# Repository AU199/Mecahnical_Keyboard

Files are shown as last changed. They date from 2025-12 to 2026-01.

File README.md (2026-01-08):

# Mecahnical Keyboard
I made this projects because I wanted to learn how software and hardware come together inside something as simple keyboard (Which I found wasn't simple at all). I wanted to also learn how to make a PCB and how to CAD with better practices. This is a Mechanical keyboard that utilizes both a main chip and a "slave" chip (a chip made to work as if it were just an i/o extender). This uses a diode-matrix for the sensing and uses the SDA and SCL channels on the "slave" chip to read and understand. 

BOM (Used an program for this to convert to a table in a .md file)
| Item | Description | Quantity | Total Price | shipping | Link | Running Total | Comments |
| --- | --- | --- | --- | --- | --- | --- | --- |
| Kailh Hotswap Switches (70 PCS) | Need for the mechanical Keyboard switches | 1 | $4.71 | | https://www.aliexpress.us/item/3256807290300019.html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 | $4.71 | |
| 0.91 INCH OLED DISPLAY MODULE | Display Module added for display functionallity | 1 | $2.40 | | https://www.aliexpress.us/item/3256807115924372.html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 | $7.07 | |
| MCP23017-E/SO | I/O expander that I need in order to make the full keyboard | 1 | $4.99 | | https://www.aliexpress.us/item/3256810374801839.html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 | $12.06 | |
| XIAO-nRF52840 | Main Chip of this keyboard | 1 | $11.77 | | https://www.aliexpress.us/item/3256808117851584.html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 | $23.83 | |
| PCB & PCBA | The total price for both making the PCB and the PCBA | 1 | $42.01 | $91.28 (FedEx Express (DDP), I can't do anything about the price, there is also a 10 dollar discount as such the grand total comes to be $123.85) | JLCPCB (CAN'T PROVIDE A LINK) | $147.68 | includes Sales tax, shipping and customes duties  |
| Key Switch | Needed for typing | 1 | $3.23 | | https://www.aliexpress.us/item/3256806499127042.html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 | $150.91 | |
| Key Caps | Needed to put on the swtiches | 1 | $8.77 | | https://www.aliexpress.us/item/3256804183268436.html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 | $159.68 | |
| Resistor Network (6PCS) | Pull up Resistor chain | 1 | $1.79 | | https://www.aliexpress.us/item/3256806684196291.html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 | $161.47 | |
| Soldering Wire (Lead Free) | Needed For Soldering | 1 | $3.65 | | https://www.aliexpress.us/item/3256810239367550.html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 | $165.12 | |
| Stabalizers | Needed for the larger keys | 1 | $6.77 | $16.50 | https://www.aliexpress.us/item/2251832533420646.html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 | $188.39 | includes Sales tax and shipping |
| |
# SHIPPING PRICE PROOF (Price is a little different since I had to make a new order, but the delivery method is still the same)   
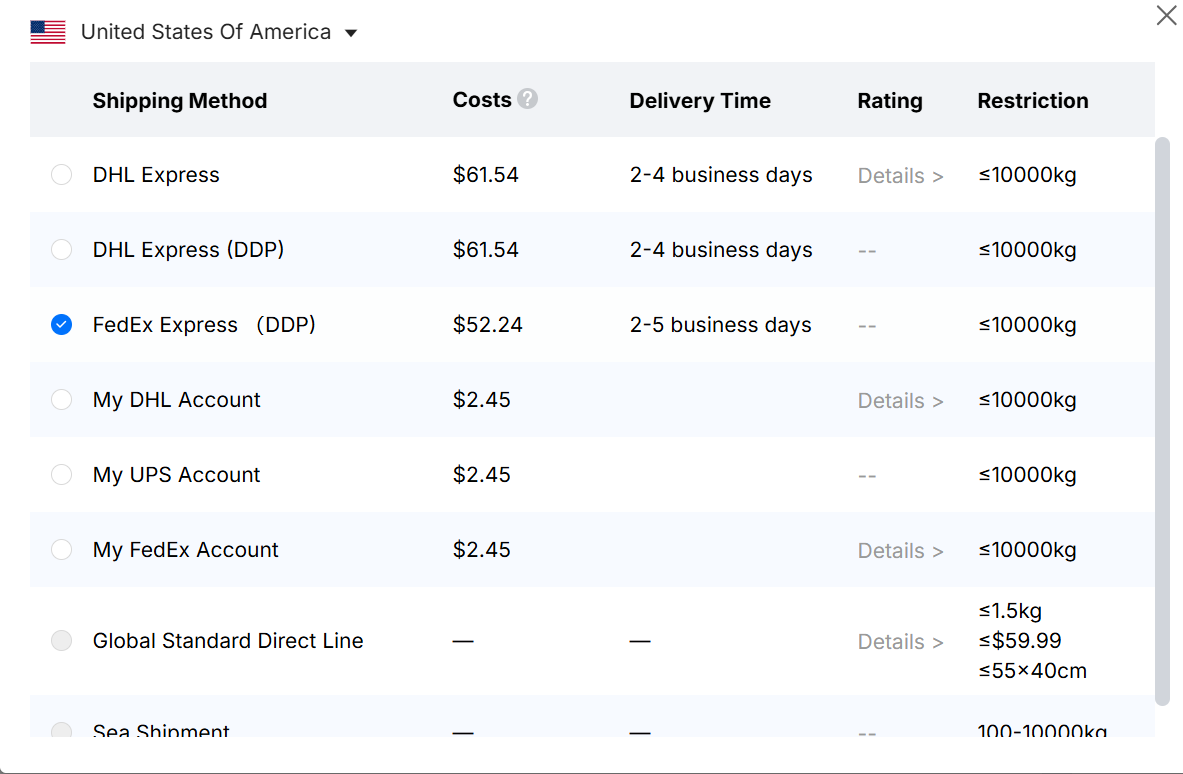
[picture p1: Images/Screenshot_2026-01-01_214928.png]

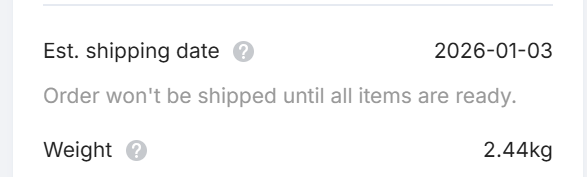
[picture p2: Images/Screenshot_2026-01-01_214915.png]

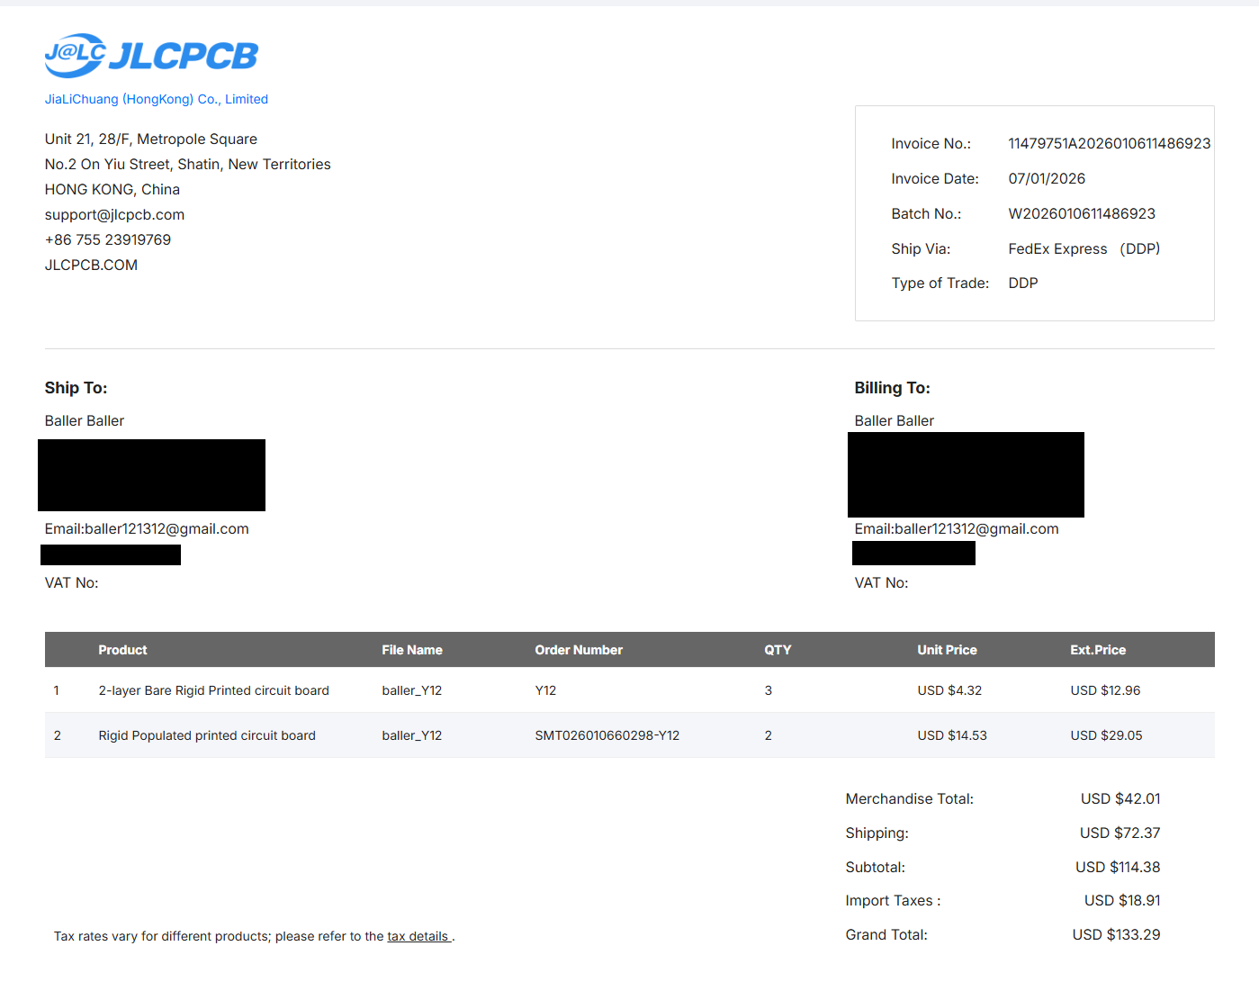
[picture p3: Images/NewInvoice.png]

# PCB Image
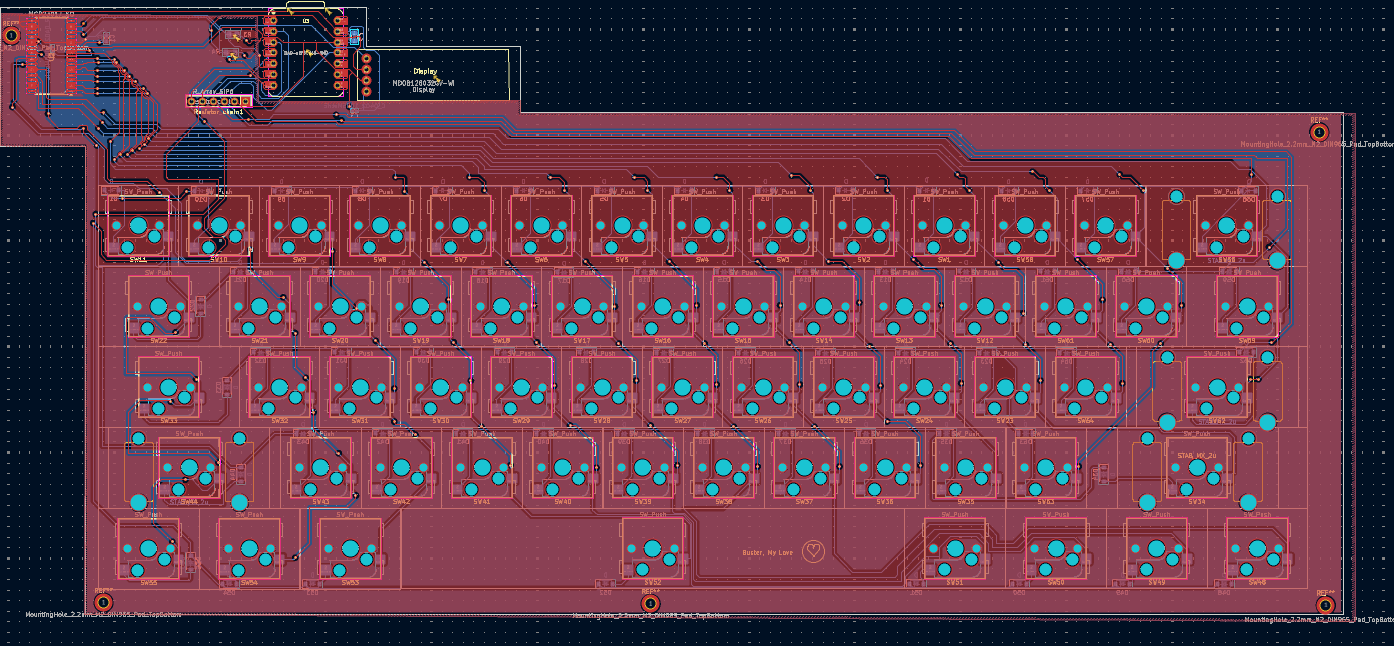
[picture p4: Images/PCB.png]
PCB Image


#CAD Image
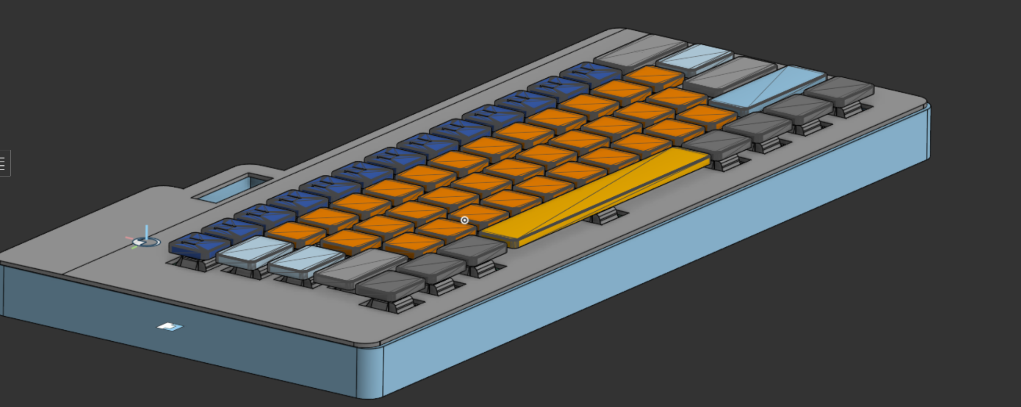
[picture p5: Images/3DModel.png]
CAD Image

# 3D Render '0'
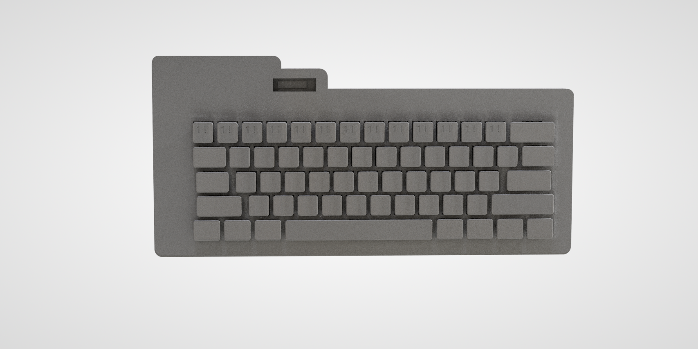
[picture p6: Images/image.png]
3D Render


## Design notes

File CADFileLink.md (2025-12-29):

# CAD link

https://cad.onshape.com/documents/e66e1d4bf8821dd6b1c940b4/w/817876546f1c3006380e8f7d/e/fd4eaec7cf626d13ad612340
THE STL FILE THAT I WANTED TO ADD WAS TOO BIG, PLEASE USE THIS LINK TO LOOK AT IT

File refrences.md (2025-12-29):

# REFRENCES

I have used AI to guide my process, I don't exactly know their sources, but I have ONLY USED AI AS A GUIDENCE TOOL (reserch, help with wiring, etc.). NO DESIGN CHOICES WERE MADE BY AI, THIS PROJECT IS COMPLETLY CADed AND ROUTED BY ME!!

Videos i used to learn about this topic:
https://youtu.be/iznKltVU1yw 
https://youtu.be/7LyziNdFlew

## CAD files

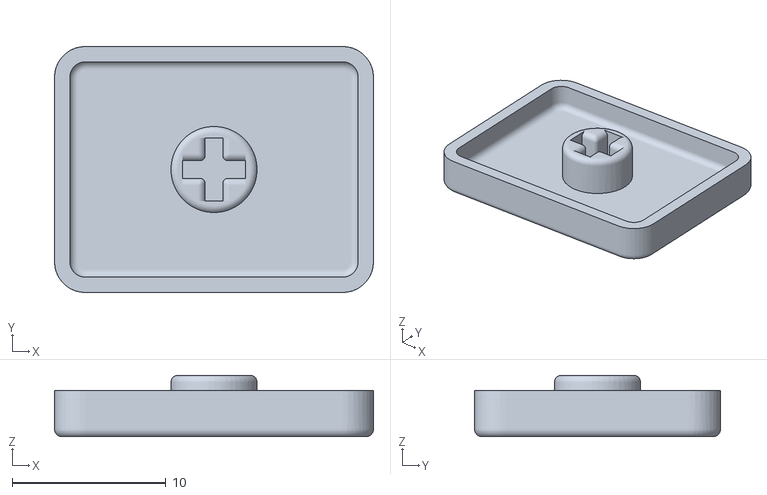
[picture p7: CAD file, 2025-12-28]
ExternalSTL/1_25x.stl
20.8 x 16.0 x 4.00

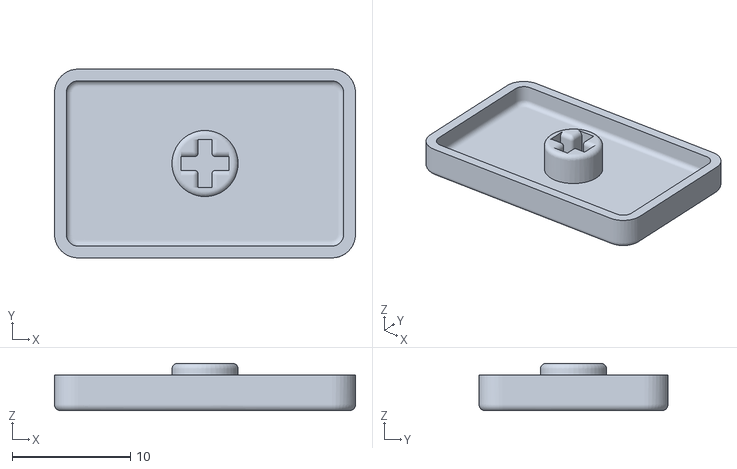
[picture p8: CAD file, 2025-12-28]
ExternalSTL/1_5x.stl
25.5 x 16.0 x 4.00

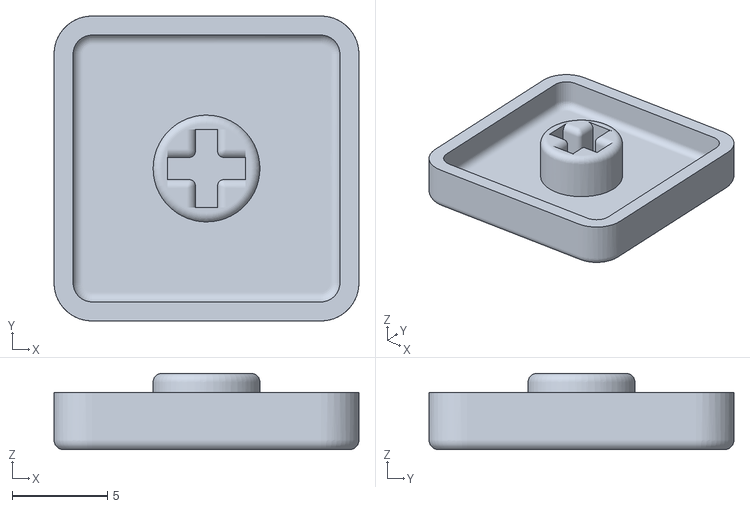
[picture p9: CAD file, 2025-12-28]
ExternalSTL/1.stl
16.0 x 16.0 x 4.00

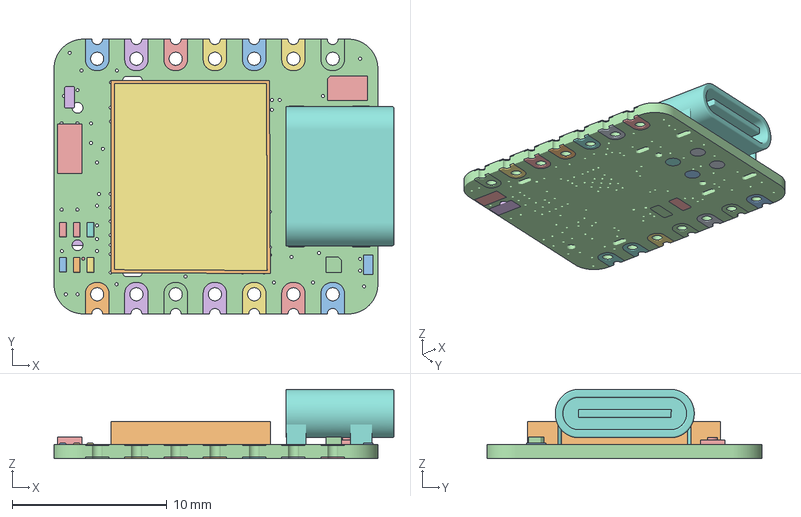
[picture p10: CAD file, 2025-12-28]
ExternalSTL/Seeed Studio XIAO nRF52840.3mf
22.0 x 17.8 x 4.47 mm
C0201
C0201_(2)
Blue_thingy_(antenna?)
R0201
R0201_(2)
SOD-523
C0201_(3)
R0201_(3)
C0201_(4)
SOT-25
C0201_(5)
R0201_(4)
USB-C_terminal
C0201_(6)
C0201_(7)
PMOS_1.0*0.6*0.35MM
C0201_(8)
C0201_(9)
C0201_(10)
C0201_(11)
C0201_(12)
C0201_(13)
C0201_(14)
X4-SMD-2.0X1.6X0.5MM
C0201_(15)
C0201_(16)
X2-SMD-1.6X1.0X0.5MM
C0201_(17)
Reset_switch
L0201
C0201_(18)
C0201_(19)
C0201_(20)
R0201_(5)
RGB_LED
C0201_(21)
SOT-25_(2)
C0201_(22)
C0201_(23)
QFN32G-0.5-5X5MM
C0201_(24)
LED-0402
R0201_(6)
BAT-
Tiny_resistor
C0201_(25)
C0201_(26)
R0201_(7)
L0201_(2)
R0201_(8)
R0201_(9)
R0201_(10)
R0201_(11)
R0201_(12)
R0201_(13)
Board
F0603
C0201_(27)
BAT+
C0201_(28)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

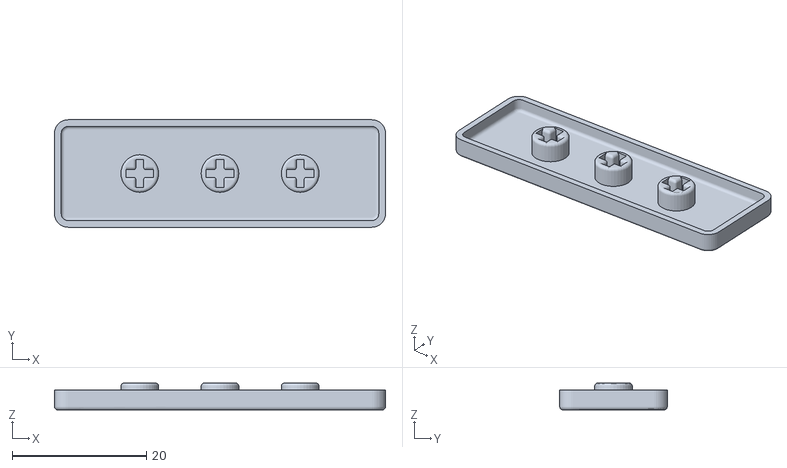
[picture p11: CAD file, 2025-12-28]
ExternalSTL/2_75x.stl
49.2 x 16.0 x 4.00

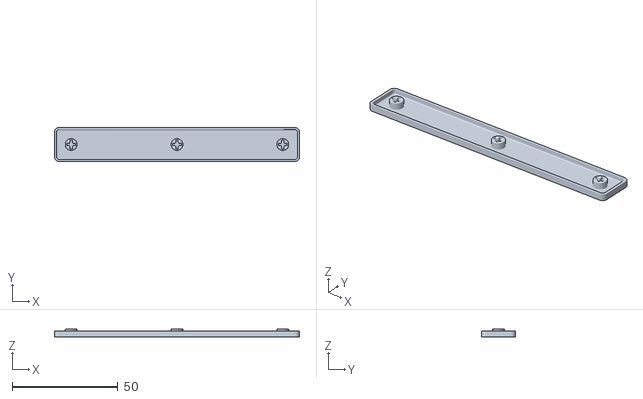
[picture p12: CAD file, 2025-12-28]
ExternalSTL/6_25x.stl
115.8 x 16.0 x 4.00

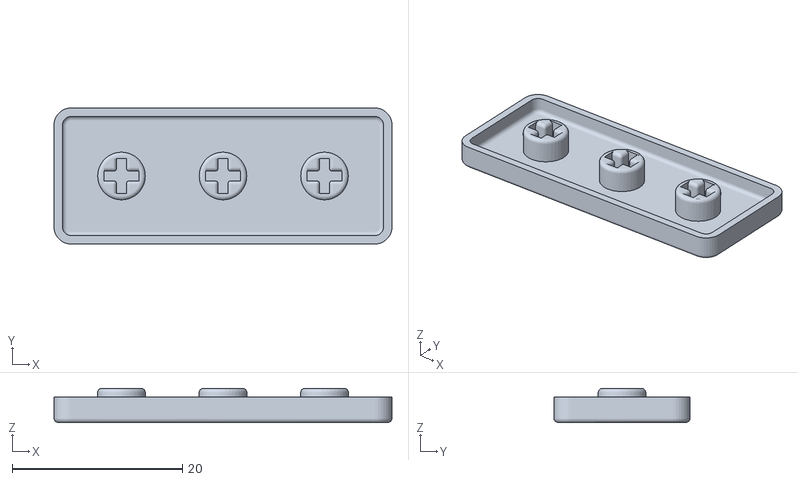
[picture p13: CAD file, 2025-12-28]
ExternalSTL/2_25x.stl
39.8 x 16.0 x 4.00

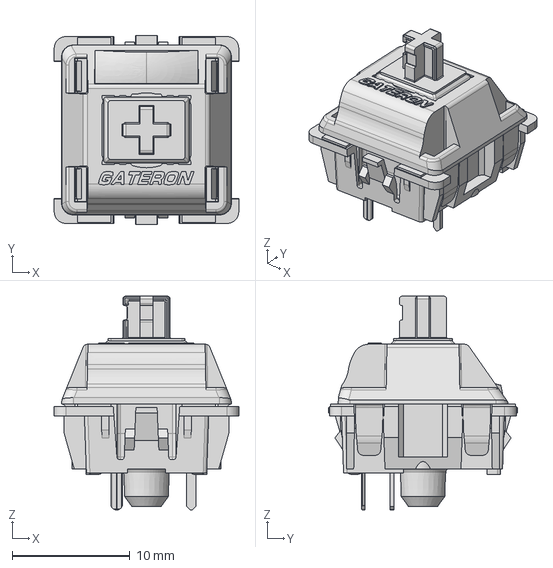
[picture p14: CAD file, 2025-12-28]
ExternalSTL/G PRO 3.0 Switch KS-9E10B055NN-Y51.stp
15.7 x 16.1 x 18.2 mm

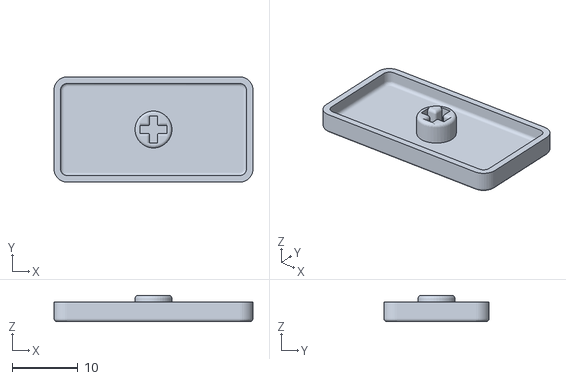
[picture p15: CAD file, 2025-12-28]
ExternalSTL/1_75x.stl
30.2 x 16.0 x 4.00

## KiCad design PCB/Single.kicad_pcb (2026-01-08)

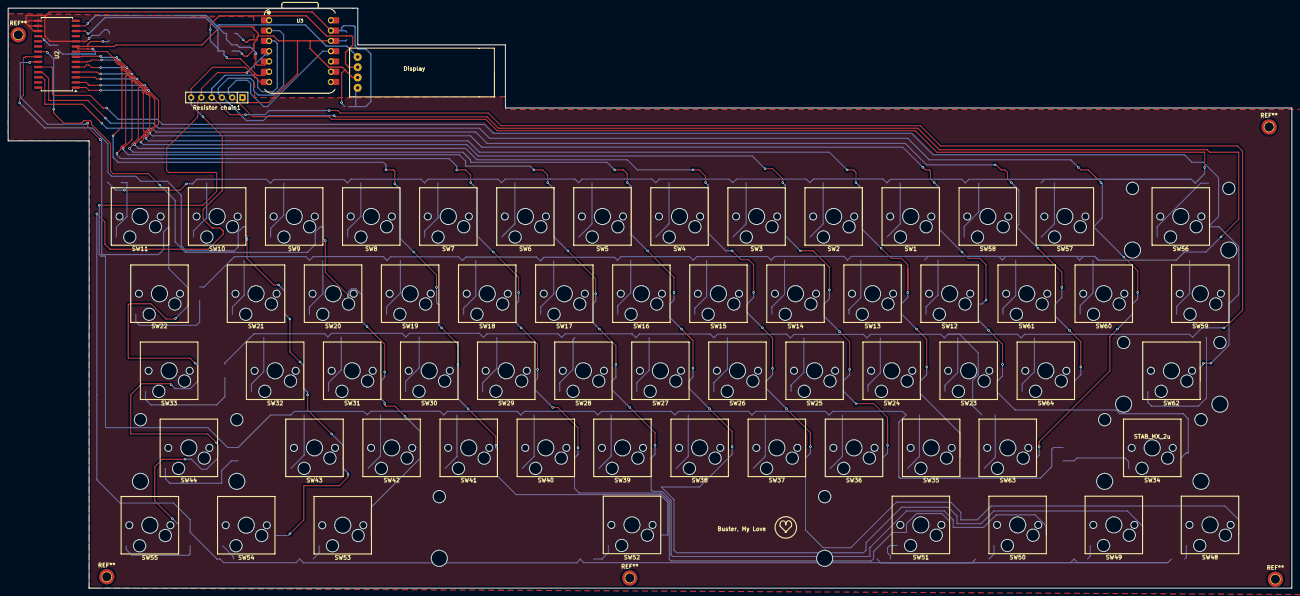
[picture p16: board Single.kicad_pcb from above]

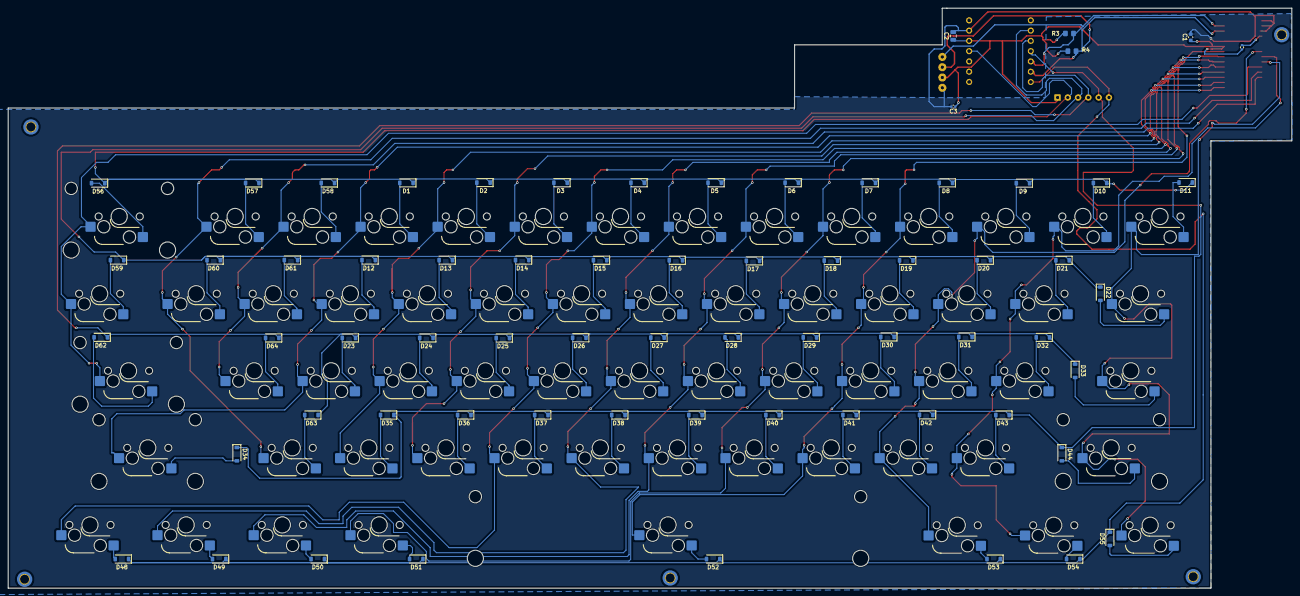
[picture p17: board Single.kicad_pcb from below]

Board: 2 copper layers, 317.3 x 143.3 mm, 132 parts (67 on the bottom side), 85 nets.

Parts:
C1: C1; C_0603_1608Metric
C2: C2; C_0805_2012Metric
C3: C_0402_1005Metric
D1, D2, D3, D4, D5, D6, D7, D8, D9, D10, D11, D12, D13, D14, D15, D16, D17, D18, D19, D20, D21, D22, D23, D24, D25, D26, D27, D28, D29, D30, D31, D32, D33, D34, D35, D36, D37, D38, D39, D40, D41, D42, D43, D44, D48, D49, D50, D51, D52, D53, D54, D55, D56, D57, D58, D59, D60, D61, D62, D63, D64: D; D_SOD-123
Display: MDOB128032GV-WI
R3, R4: R_45deg; R_0805_2012Metric_Pad1.20x1.40mm_HandSolder
R5: R_0402_1005Metric
Resistor chain1: R_Array_SIP6
SW1, SW2, SW3, SW4, SW5, SW6, SW7, SW8, SW9, SW10, SW11, SW12, SW13, SW14, SW15, SW16, SW17, SW18, SW19, SW20, SW21, SW23, SW24, SW25, SW26, SW27, SW28, SW29, SW30, SW31, SW32, SW35, SW36, SW37, SW38, SW39, SW40, SW41, SW42, SW43, SW57, SW58, SW60, SW61, SW63, SW64: SW_Push; SW_Hotswap_Kailh_MX_1.00u
SW22, SW59: SW_Push; SW_Hotswap_Kailh_MX_1.50u
SW33: SW_Push; SW_Hotswap_Kailh_MX_1.75u
SW34: SW_Push; SW_Hotswap_Kailh_MX_2.75u
SW44, SW62: SW_Push; SW_Hotswap_Kailh_MX_2.25u
SW48, SW49, SW50, SW51, SW53, SW54, SW55: SW_Push; SW_Hotswap_Kailh_MX_1.25u
SW52: SW_Push; SW_Hotswap_Kailh_MX_6.25u
SW56: SW_Push; SW_Hotswap_Kailh_MX_2.00u
U2: MCP23017_SO; SOIC-28W_7.5x17.9mm_P1.27mm
U3: XIAO-nRF52840-SMD; XIAO-nRF52840-DIP

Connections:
3V3: C1.1, C2.1, C3.1, Display.3, R3.1, R4.2, R5.1, Resistor chain1.1, U2.9 (VDD), U3.12 (3V3)
Col 1: SW56.1, SW59.1, SW62.1, U2.24 (GPA3)
Col 2: SW57.1, SW60.1, SW63.1, U2.25 (GPA4)
Col 3: SW58.1, SW61.1, SW64.1, U2.26 (GPA5)
Col 4: SW1.1, SW12.1, SW23.1, SW34.1, U2.1 (GPB0)
Col 5: SW2.1, SW13.1, SW24.1, SW35.1, U2.2 (GPB1)
Col 6: SW3.1, SW14.1, SW25.1, SW36.1, U2.3 (GPB2)
Col 7: SW4.1, SW15.1, SW26.1, SW37.1, SW48.1, U2.4 (GPB3)
Col 8: SW5.1, SW16.1, SW27.1, SW38.1, SW49.1, U2.5 (GPB4)
Col 9: SW6.1, SW17.1, SW28.1, SW39.1, SW50.1, U2.6 (GPB5)
Col 10: SW7.1, SW18.1, SW29.1, SW40.1, SW51.1, U2.7 (GPB6)
Col 11: SW8.1, SW19.1, SW30.1, SW41.1, SW52.1, U2.8 (GPB7)
Col 12: SW9.1, SW20.1, SW31.1, SW42.1, SW53.1, U2.21 (GPA0)
Col 13: SW10.1, SW21.1, SW32.1, SW43.1, SW54.1, U2.22 (GPA1)
Col 14: SW11.1, SW22.1, SW33.1, SW44.1, SW55.1, U2.23 (GPA2)
GND: C1.2, C2.2, C3.2, Display.4, U2.10 (VSS), U2.15 (A0), U2.16 (A1), U2.17 (A2), U3.13 (GND)
unnamed: D1.2 (A), SW1.2
unnamed: D2.2 (A), SW2.2
unnamed: D3.2 (A), SW3.2
unnamed: D4.2 (A), SW4.2
unnamed: D5.2 (A), SW5.2
unnamed: D6.2 (A), SW6.2
unnamed: D7.2 (A), SW7.2
unnamed: D8.2 (A), SW8.2
unnamed: D9.2 (A), SW9.2
unnamed: D10.2 (A), SW10.2
unnamed: D11.2 (A), SW11.2
unnamed: D12.2 (A), SW12.2
unnamed: D13.2 (A), SW13.2
unnamed: D14.2 (A), SW14.2
unnamed: D15.2 (A), SW15.2
unnamed: D16.2 (A), SW16.2
unnamed: D17.2 (A), SW17.2
unnamed: D18.2 (A), SW18.2
unnamed: D19.2 (A), SW19.2
unnamed: D20.2 (A), SW20.2
unnamed: D21.2 (A), SW21.2
unnamed: D22.2 (A), SW22.2
unnamed: D23.2 (A), SW23.2
unnamed: D24.2 (A), SW24.2
unnamed: D25.2 (A), SW25.2
unnamed: D26.2 (A), SW26.2
unnamed: D27.2 (A), SW27.2
unnamed: D28.2 (A), SW28.2
unnamed: D29.2 (A), SW29.2
unnamed: D30.2 (A), SW30.2
unnamed: D31.2 (A), SW31.2
unnamed: D32.2 (A), SW32.2
unnamed: D33.2 (A), SW33.2
unnamed: D34.2 (A), SW34.2
unnamed: D35.2 (A), SW35.2
unnamed: D36.2 (A), SW36.2
unnamed: D37.2 (A), SW37.2
unnamed: D38.2 (A), SW38.2
unnamed: D39.2 (A), SW39.2
unnamed: D40.2 (A), SW40.2
unnamed: D41.2 (A), SW41.2
unnamed: D42.2 (A), SW42.2
unnamed: D43.2 (A), SW43.2
unnamed: D44.2 (A), SW44.2
unnamed: D48.2 (A), SW48.2
unnamed: D49.2 (A), SW49.2
unnamed: D50.2 (A), SW50.2
unnamed: D51.2 (A), SW51.2
unnamed: D52.2 (A), SW52.2
unnamed: D53.2 (A), SW53.2
unnamed: D54.2 (A), SW54.2
unnamed: D55.2 (A), SW55.2
unnamed: D56.2 (A), SW56.2
unnamed: D57.2 (A), SW57.2
unnamed: D58.2 (A), SW58.2
unnamed: D59.2 (A), SW59.2
unnamed: D60.2 (A), SW60.2
unnamed: D61.2 (A), SW61.2
unnamed: D62.2 (A), SW62.2
unnamed: D63.2 (A), SW63.2
unnamed: D64.2 (A), SW64.2
Reset: R5.2, U2.18 (~RESET)
Row 1: D1.1 (K), D2.1 (K), D3.1 (K), D4.1 (K), D5.1 (K), D6.1 (K), D7.1 (K), D8.1 (K), D9.1 (K), D10.1 (K), D11.1 (K), D56.1 (K), D57.1 (K), D58.1 (K), Resistor chain1.2, U3.11 (P1.15_D10_MOSI)
Row 2: D12.1 (K), D13.1 (K), D14.1 (K), D15.1 (K), D16.1 (K), D17.1 (K), D18.1 (K), D19.1 (K), D20.1 (K), D21.1 (K), D22.1 (K), D59.1 (K), D60.1 (K), D61.1 (K), Resistor chain1.3, U3.2 (P0.03_A1_D1)
Row 3: D23.1 (K), D24.1 (K), D25.1 (K), D26.1 (K), D27.1 (K), D28.1 (K), D29.1 (K), D30.1 (K), D31.1 (K), D32.1 (K), D33.1 (K), D62.1 (K), D63.1 (K), D64.1 (K), Resistor chain1.4, U3.3 (P0.28_A2_D2)
Row 4: D34.1 (K), D35.1 (K), D36.1 (K), D37.1 (K), D38.1 (K), D39.1 (K), D40.1 (K), D41.1 (K), D42.1 (K), D43.1 (K), D44.1 (K), Resistor chain1.5, U3.4 (P0.29_A3_D3)
Row 5: D48.1 (K), D49.1 (K), D50.1 (K), D51.1 (K), D52.1 (K), D53.1 (K), D54.1 (K), D55.1 (K), Resistor chain1.6, U3.7 (P1.11_D6_TX)
SCL: Display.2, R4.1, U2.12 (SCK), U3.6 (P0.05_A5_D5_SCL)
SDA: Display.2, R3.2, U2.13 (SDA), U3.5 (P0.04_A4_D4_SDA)

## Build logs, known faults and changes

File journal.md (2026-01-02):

<!--
  This journal is auto generated by Hack Club Blueprint.
-->

## 12/15/2025 - Learned the Ideas, and imported libraries  

_Time spent: 2.0h_  

I downloaded KiCad, and read the starting hackclub documentation on building a small keyboard. I had to work to download the libraries and had to research on how to do that. I started the schematics for the left part of the keyboard.


## 12/16/2025 2 PM - Started routing the PCB  

_Time spent: 3.0h_  

I started routing the PCB, but I faced a lot of issues with errors popping. I also found out about how netting actually works and what is it's uses in routing. I also found that the I was conflicted between the split design and making one whole keyboard. I ended up choosing the split design. 

## 12/16/2025 5 PM - Changed the design  

_Time spent: 2.0h_  

I felt that it would be better if this was a single mechanical keyboard insted of two. As such I am going to be building a keyboard with two board, one main and the other acting as a slave-board. 

## 12/17/2025 - Started PCB, found flaw  

_Time spent: 3.0h_  

I started making the PCB and had finished routing when I realized that in my footprints I hadn't accounted for the fact that keys takes up space. this means that I have to change my keycaps to different type. 	

## 12/21/2025 - Finished making the general pcb, started putting the diodes  

_Time spent: 3.0h_  

I understood what went wrong, as such using cherry switches I make sure that the footprints were actual to the real world. Now I have started the process of setting up the diodes for each switch. I have also started researching the places from which I can buy my switches and other items.

## 12/23/2025 - Finished routing the PCB, looking for parts  

_Time spent: 5.0h_  

Today I finally finished my pcb routing, and created a better border in order to reduce the size of the pcb. I also started researching PCBA services since I don't want to solder such small parts to my pcb. I have looked at JLCPCB, and found that they are the cheapest option. I am slowey coming to the end of the computer based design process.

## 12/26/2025 - Started CADing the case   

_Time spent: 3.0h_  

Using onshape, I have started CADing the base of the keyboard. I also started trying to price optimize with my product selection. I have tried finding everything in amazon just so that I try and reduce costs for delivery fee. 

## 12/27/2025 - Changed the CAD, and at the end of computer stuff  

_Time spent: 4.0h_  

I have finished my cad along with switches and other items, I tweaked my design a little. I have finished my BOM, and now I am onto finishing my code for my keyboard. I am very close to finishing my project. I will add one of the 3D renders that I made using some random website :/.


## 12/28/2025 - Done with computer based items  

_Time spent: 4.0h_  

I have Finished writing and making my Github. I am now going to be submitting. Now the wait will begin. I have learned a lot from this. I have only made basic PCBs before this and never actually manufactured it. 

## 1/1/2026 - Shipping information  

_Time spent: 0.1h_  

As per the instructions of the person who reviewed this project, they told me to provide proof that the shipping option I had selected was the cheapest one. though the price of this one is a little lower (since for some reason JLC didn't allow me to go back and look at my order and take a screenshot of that) the idea and the problem is the same. Since my project weight is above the GSDL limit, I am using the next cheapest option FEDEX Express DDP, since that is the only option available that is cheap

These are the following prices and my project weight. I have the options selected as 5 PCBs and 2 PCBAs, the PCBAs are required as the things on there are SMDs resistors and diodes that would be really tedious to route again as well as resulting in a bigger overall pcb, which would bring up the same problem of dimensions.
(Don't worry about the hours, I had to add it because 0 hours wasn't allowed) (I love writing scholarship essays =) )

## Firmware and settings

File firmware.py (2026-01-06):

import board
import time
import math
import busio
import adafruit_ssd1306

from kmk.kmk_keyboard import KMKKeyboard
from kmk.scanners import DiodeOrientation
from kmk.keys import KC

from digitalio import DigitalInOut, Direction, Pull

from adafruit_mcp230xx.mcp23017 import MCP23017


i2c = busio.I2C(board.D5,board.D4,frequency = 400000)
mcp = MCP23017(i2c,adress=0x20)
W,H = 128,32
display = adafruit_ssd1306.SSD1306_I2C(W,H,i2c,addr = 0x3c)
display.fill(0)
display.text("HELLO WORLD :)",0,0,1)
display.show()

NumKeys, Orientation = 61,DiodeOrientation.COL2ROW


class Visualizer:
    def __init__(self,display):
        self.d = display
        self.layer = 0
        self.caps = False
        
        self.bars = 16
        self.barHeights = [0]*16
        self.barTargets = [0]*16
        self.barVels = [0]*16
        
        self.lastKeyPress = time.monotonic()
        self.typingEnergy = 0
        self.wpm = 0
        self.keyCount = 0
        
        self.beat_phase=0
        self.mode = 'ambient'
        
    def bootAnimation(self):
        
        for step in range(H):
            self.d.fill(0)
            for i in range(self.bars):
                bar_h = min(step+(i*2),H)
                x = i*(W//self.bars)
                self.d.fill_rect(x,H-bar_h,(W//self.bars)-1,bar_h,1)
            self.d.show()
            time.sleep(0.02)
            
        self.d.fill(0)
        self.d.text("WELCOME",20,12,1)
        self.d.show()
        time.sleep(0.5)
    
    def generateAmbient(self):
        now = time.monotonic()
        
        for i in range(self.bars):
            wave1 = math.sin(now*2 + i*0.5)*0.3
            wave2 = math.sin(now *1.5 + i*0.3)*0.2
            wave3 = math.sin(now*3 + i*0.7)*0.15
            combined = wave1+wave2+wave3+1
            combined /=2
            self.barTargets[i] = int(combined*H*0.6)
            
    def updateBars(self):
        for i in range(self.bars):
            diff = self.barTargets[i] - self.barHeights[i]
            self.barVels[i] = diff*0.3
            self.barVels[i] *= 0.7
            
            self.barHeights[i] += self.barVels[i]
            self.barHeights[i] = max(0,min(H,self.barHeights[i]))
            
    def drawBars(self):
        self.d.fill(0)
        
        barW = W//self.bars
        
        for i in range(self.bars):
            h = int(self.barHeights[i])
            x = i * barW
            if h>0:
                self.d.fill.rect(x,H-h,barW-1,h,1)
                if h>2:
                    self.d.fill.rect(x,H-h-2,barW-1,1,1)
                    
        self.d.show()
    
    def update(self):
        
        self.generateAmbient()
        self.updateBars()
        self.drawBars()
        
viz = Visualizer(display)
    
class Scanner:
    def __init__(self,keys,cols,rows,orientation):
        self.cols = cols
        self.rows = rows
        self.orientation = True if orientation == DiodeOrientation.COL2ROW else False #True when COL2ROW and False when ROW2COL
        self.numberOfKeys = keys
        self._states = [False]*self.numberOfKeys
        self._debounce = [False]*self.numberOfKeys
        
        
        if self.orientation:
            for c in cols:
                c.direction = Direction.OUTPUT
                c.value = True
            for r in rows:
                r.direction = Direction.INPUT
                r.pull = Pull.UP
                
        else:
            for r in rows:
                r.direction = Direction.OUTPUT
                r.value = True
                
            for c in cols:
                c.direction = Direction.INPUT
                c.pull = Pull.UP
    def scan(self):
        events = []

        
        if self.orientation:
            for ci,c in enumerate(self.cols):
                c.value = False
                for ri,r in enumerate(self.rows):
                    idx = ci * len(self.rows) + ri
                    state = not r.value
                    
                    if state != self._states[idx]:
                        self._debounce[idx] += 1
                        if self._debounce[idx] >= 2:
                            self._states[idx] = state
                            self._debounce[idx] = 0
                            events.append((idx,state))
                    else:
                        self._debounce[idx] = 0
                c.value = True
        else:
            for ri,r in enumerate(self.rows):
                r.value = False
                for ci,c in enumerate(self.cols):
                    idx = ri * len(self.cols) + ci
                    state = not c.value
                    
                    if state != self._states[idx]:
                        self._debounce[idx] += 1
                        if self._debounce[idx] >= 2:
                            self._states[idx] = state
                            self._debounce[idx] = 0
                            events.append((idx,state))
                    else:
                        self._debounce[idx] = 0
                r.value = True
        return events
    
cols = [
    mcp.get_pin(3), mcp.get_pin(4), mcp.get_pin(5),    
    mcp.get_pin(8), mcp.get_pin(9), mcp.get_pin(10),   
    mcp.get_pin(11), mcp.get_pin(12), mcp.get_pin(13), 
    mcp.get_pin(14), mcp.get_pin(15),                 
    mcp.get_pin(0), mcp.get_pin(1), mcp.get_pin(2),    
]

rows = [
    DigitalInOut(board.D10),
    DigitalInOut(board.D1),
    DigitalInOut(board.D2),
    DigitalInOut(board.D3),
    DigitalInOut(board.D6)    
]

class VisualizerKB(KMKKeyboard):
    def __init__(self):
        super.__init__()
        self.prevLayer = 0
        self.counter =0
        
    def beforeMatrixScan(self,kb):
        self.counter +=1
        if self.counter >=5:
            self.counter = 0
            viz.update()
        return super().beforeMatrixScan(kb)

    



kb = VisualizerKB()
kb.matrix = Scanner(NumKeys,cols,rows,Orientation)
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

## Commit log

2025-12-26 Added all PCB files
    [Single.kicad_pcb, Single.kicad_sch, Single.step]
2025-12-26 Moved everything into the PCB folder
    [Single.kicad_pcb, Single.kicad_sch, Single.step]
2025-12-28 Added the images and stl file
    [BOM.csv]
2025-12-28 added the new keyboard Assembly
2025-12-28 Updated the README
    [BOM.csv]
2025-12-28 Added a few items and the library that was used
    [BOM.csv]
2025-12-28 Add CAD file link to CADFileLink.txt
2025-12-28 Added firmware
    [BOM.csv]
2025-12-28 Add note regarding STL file size and link
    Added a note about the STL file size and provided a link.
2025-12-28 Add PCB, CAD, and 3D render images to README
    Added images of PCB, CAD, and a 3D render to the README.
2025-12-28 fixed README
    [BOM.csv]
2025-12-28 Updated both README and BOM
    [BOM.csv]
2025-12-28 ALI EXPRESS
    [BOM.csv]
2025-12-29 Add CAD file link, update README with improved BOM formatting, and correct references
    [BOM.csv]
2025-12-29 Revise PCB and PCBA cost information
    Updated the PCB and PCBA cost details in the README.
2025-12-29 Fix formatting and update PCB cost details in README
2025-12-31 Clarify BOM details and pricing notes in README
    Updated the README to clarify the BOM and added notes about pricing.
2026-01-02 Fix formatting and descriptions in README.md
    Updated the README to correct formatting and clarify item descriptions in the BOM.
2026-01-03 Add shipping price proof and images section
    Added shipping price proof section and PCB/CAD images.
2026-01-06 Added all files required for the display based keyboard
    [BOM.csv, Single.kicad_pcb, Single.step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]
2026-01-08 Refactor code structure for improved readability and maintainability
    [BOM.csv, Single.kicad_pcb]
2026-01-08 updated BOM
2026-01-08 updated gerber
